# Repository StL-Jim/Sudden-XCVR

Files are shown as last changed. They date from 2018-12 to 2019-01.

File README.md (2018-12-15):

# Sudden-XCVR

These are the EagleCAD schematics and board files for the QRP Transceiver designed and built by Pete Julino N6QW called the Sudden Transceiver.  

I am very new to building a truly scratch built rig, so any suggestions, comments, corrections are greatly appreciated.

Read about the Sudden Scratch Built SSB Transceiver - http://www.n6qw.com/Sudden.html

I use a style of construction coined by Chuck Adams K7QO called 'Muppet Style', you can learn about this style of building from Chuck's YouTube channel

* https://www.youtube.com/watch?v=O6AmT1trO60

As I progress along I'll be adding PDF of the schematics and boards as well as the EagleCAD parts library I use.

73 - AE0BZ

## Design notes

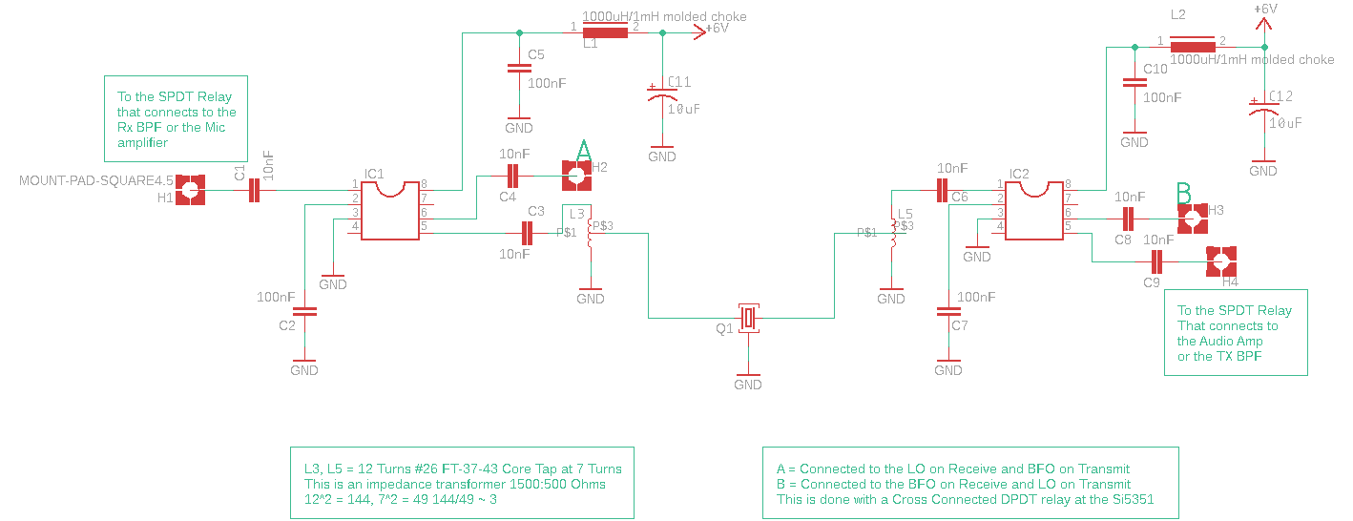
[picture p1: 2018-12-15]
Sudden_XCVR_IF_Module_Schematic.png

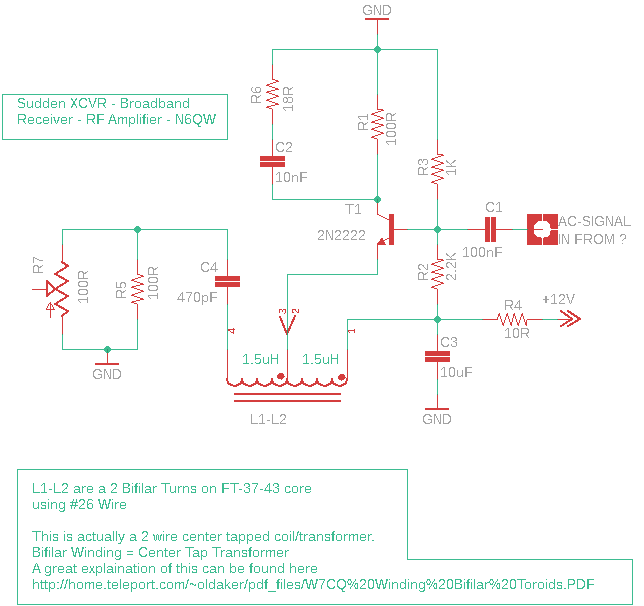
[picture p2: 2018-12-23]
broadband_receiver_rf_amp.png

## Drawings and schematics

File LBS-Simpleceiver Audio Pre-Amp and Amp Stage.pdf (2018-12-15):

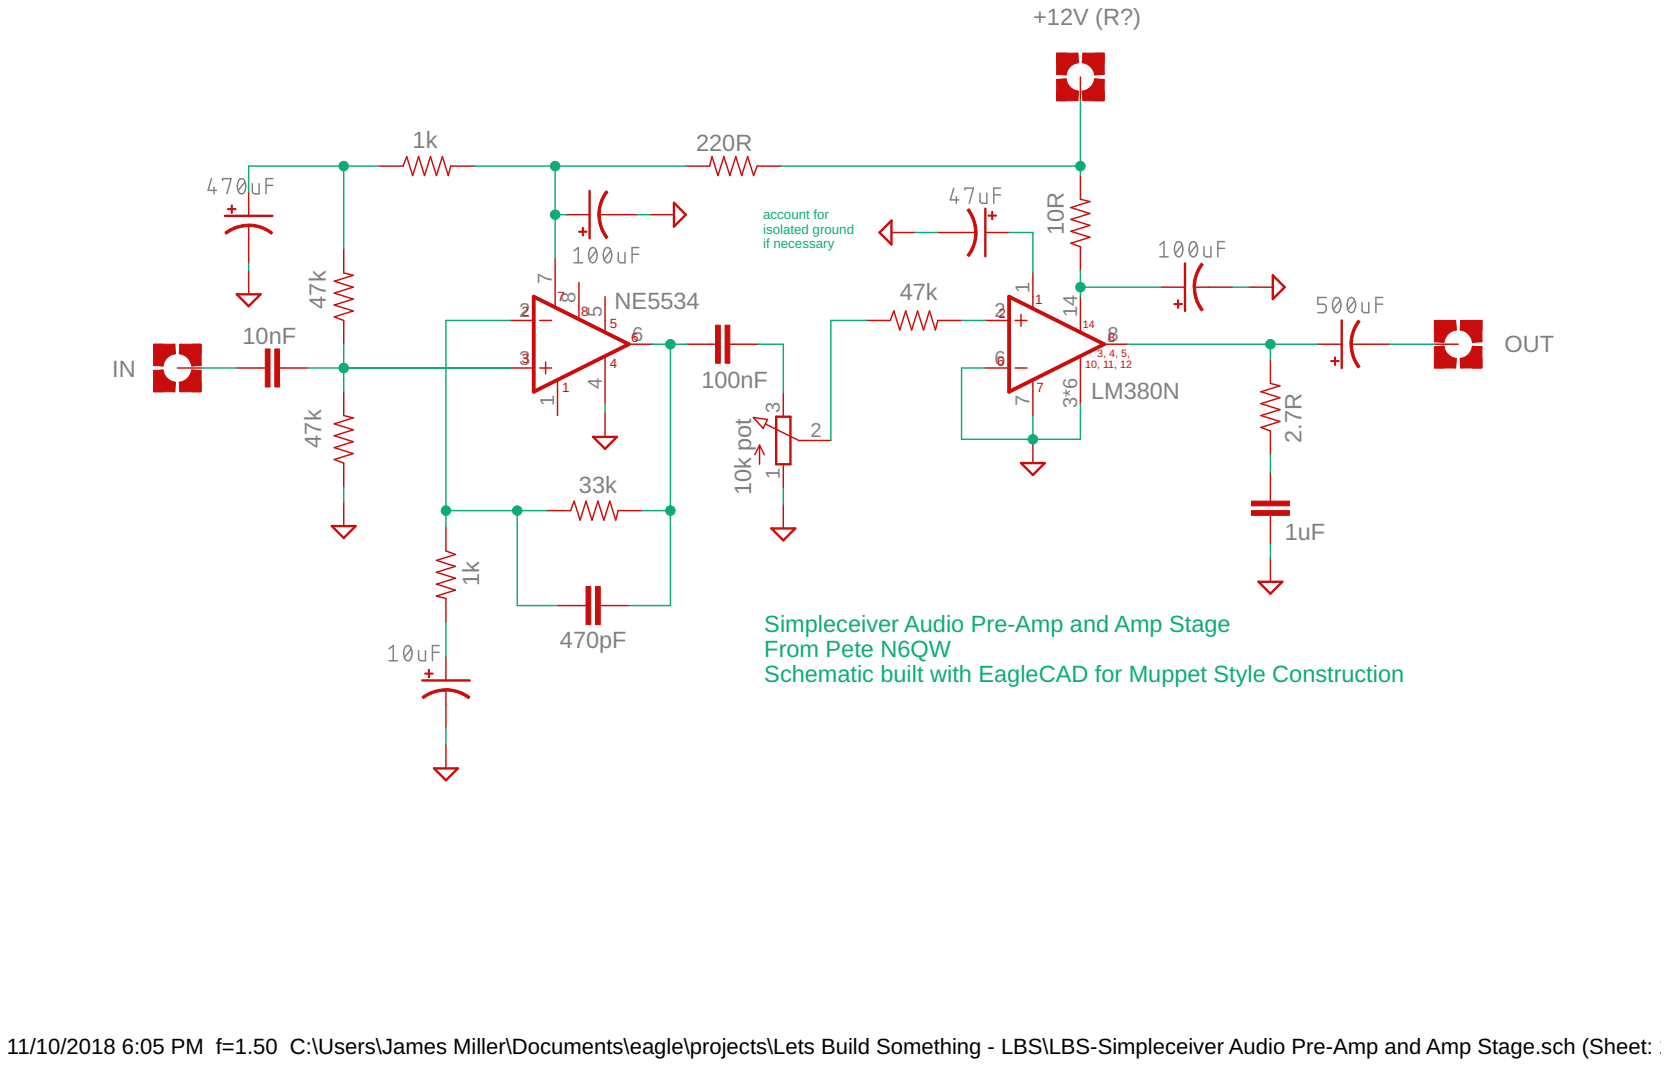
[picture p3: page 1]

Simpleceiver Audio Pre-Amp and Amp Stage
From Pete N6QW
Schematic built with EagleCAD for Muppet Style Construction

11/10/2018 6:05 PM f=1.50 C:\Users\James Miller\Documents\eagle\projects\Lets Build Something - LBS\LBS-Simpleceiver Audio Pre-Amp and Amp Stage.sch (Sheet: 1/1)

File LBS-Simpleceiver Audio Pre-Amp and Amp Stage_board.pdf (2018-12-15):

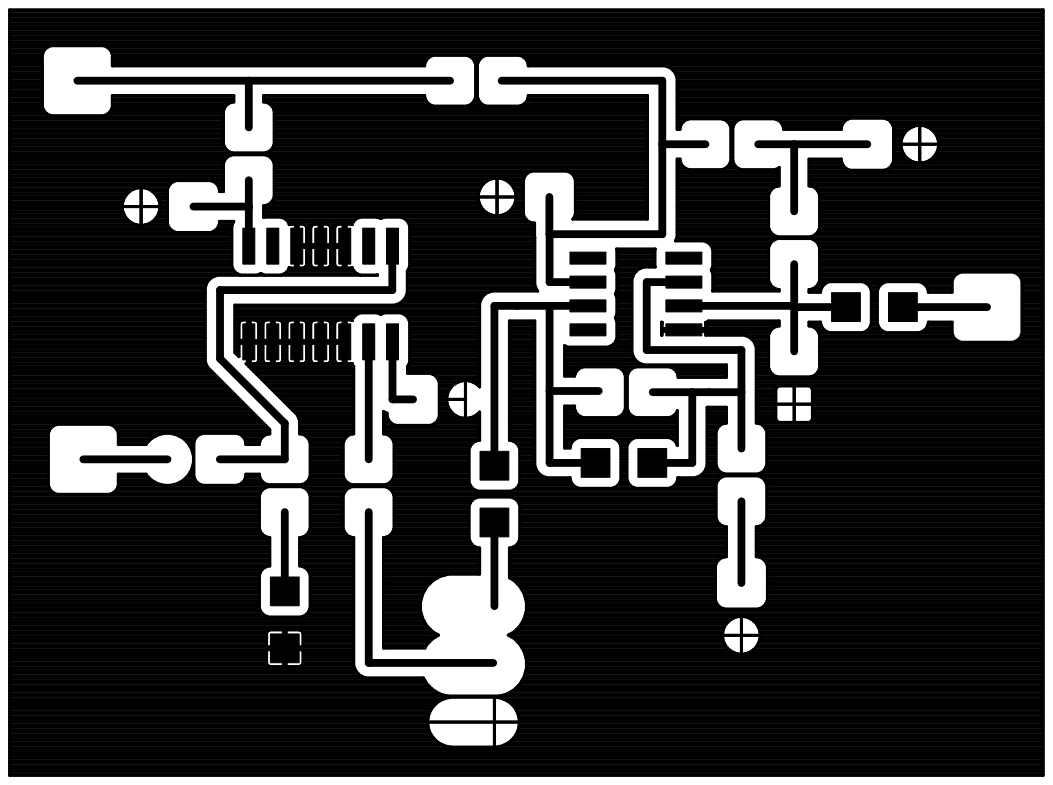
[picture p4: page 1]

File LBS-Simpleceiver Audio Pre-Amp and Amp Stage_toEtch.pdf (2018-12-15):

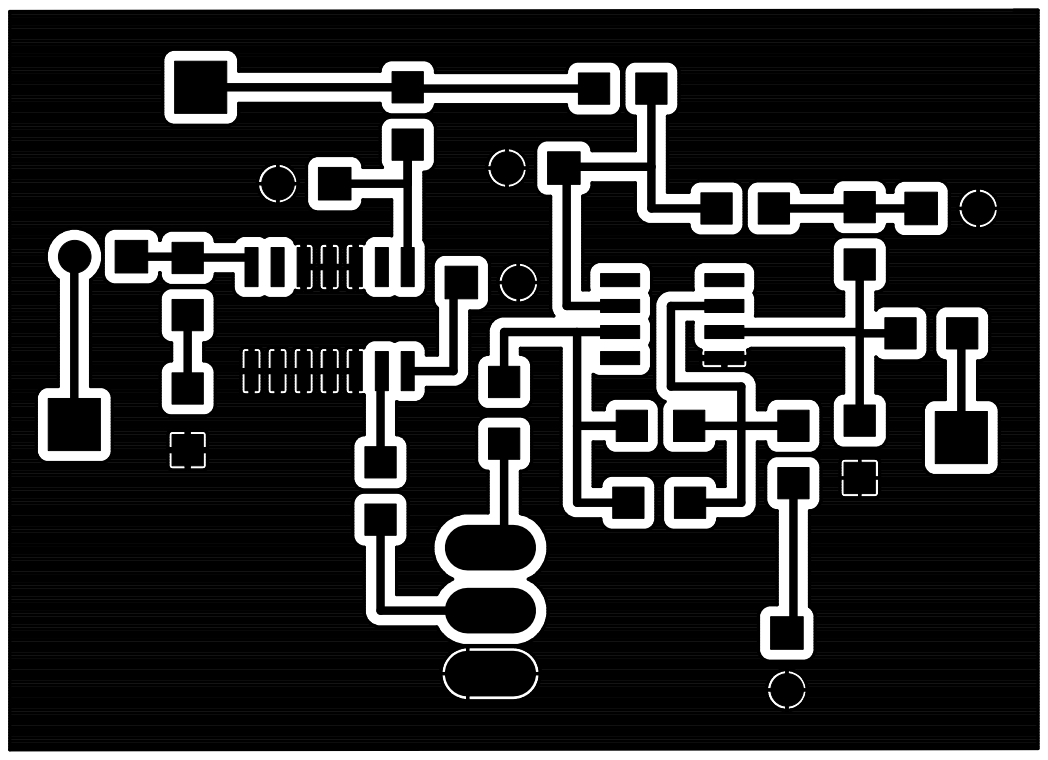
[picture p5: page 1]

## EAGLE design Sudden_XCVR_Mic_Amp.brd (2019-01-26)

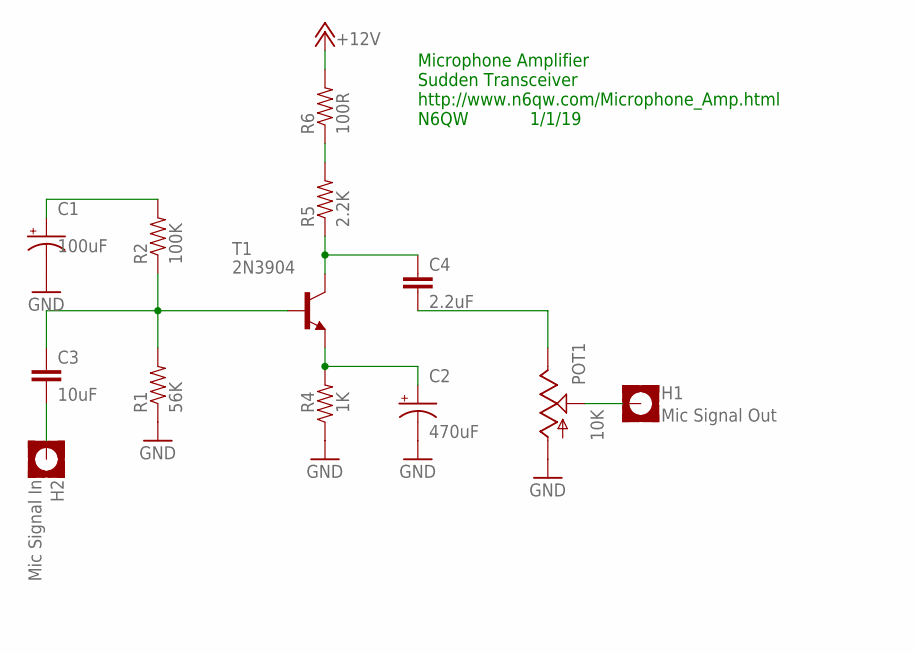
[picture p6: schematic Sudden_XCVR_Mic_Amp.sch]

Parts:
C1: 100uF; CAP-POLARIZED
C2: 470uF; CAP-POLARIZED
C3: 10uF; CAP-MEDIUM-MUPPET
C4: 2.2uF; CAP-MEDIUM-MUPPET
H1: Mic Signal Out; PAD-SQUARE
H2: Mic Signal In; PAD-SQUARE
P+1: +12V; POWER-IN-PAD
POT1: 10K; POT-TRIMM-4
R1: 56K; RESITOR-MUPPET
R2: 100K; RESITOR-MUPPET
R4: 1K; RESITOR-MUPPET
R5: 2.2K; RESITOR-MUPPET
R6: 100R; RESITOR-MUPPET
T1: 2N3904; TO92

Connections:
+12V: P+1.VCC, R6.P$2 (2)
GND: C1.2 (-), C2.2 (-), POT1.A, R1.P$1 (1), R4.P$1 (1)
unnamed: C4.1, R5.P$1 (1), T1.1 (C)
unnamed: C2.1 (+), R4.P$2 (2), T1.3 (E)
unnamed: C4.2, POT1.E
unnamed: C3.1, R1.P$2 (2), R2.P$1 (1), T1.2 (B)
unnamed: C1.1 (+), R2.P$2 (2)
unnamed: R5.P$2 (2), R6.P$1 (1)
unnamed: H1.PAD, POT1.S
unnamed: C3.2, H2.PAD

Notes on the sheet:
Microphone Amplifier Sudden Transceiver http://www.n6qw.com/Microphone_Amp.html N6QW 1/1/19

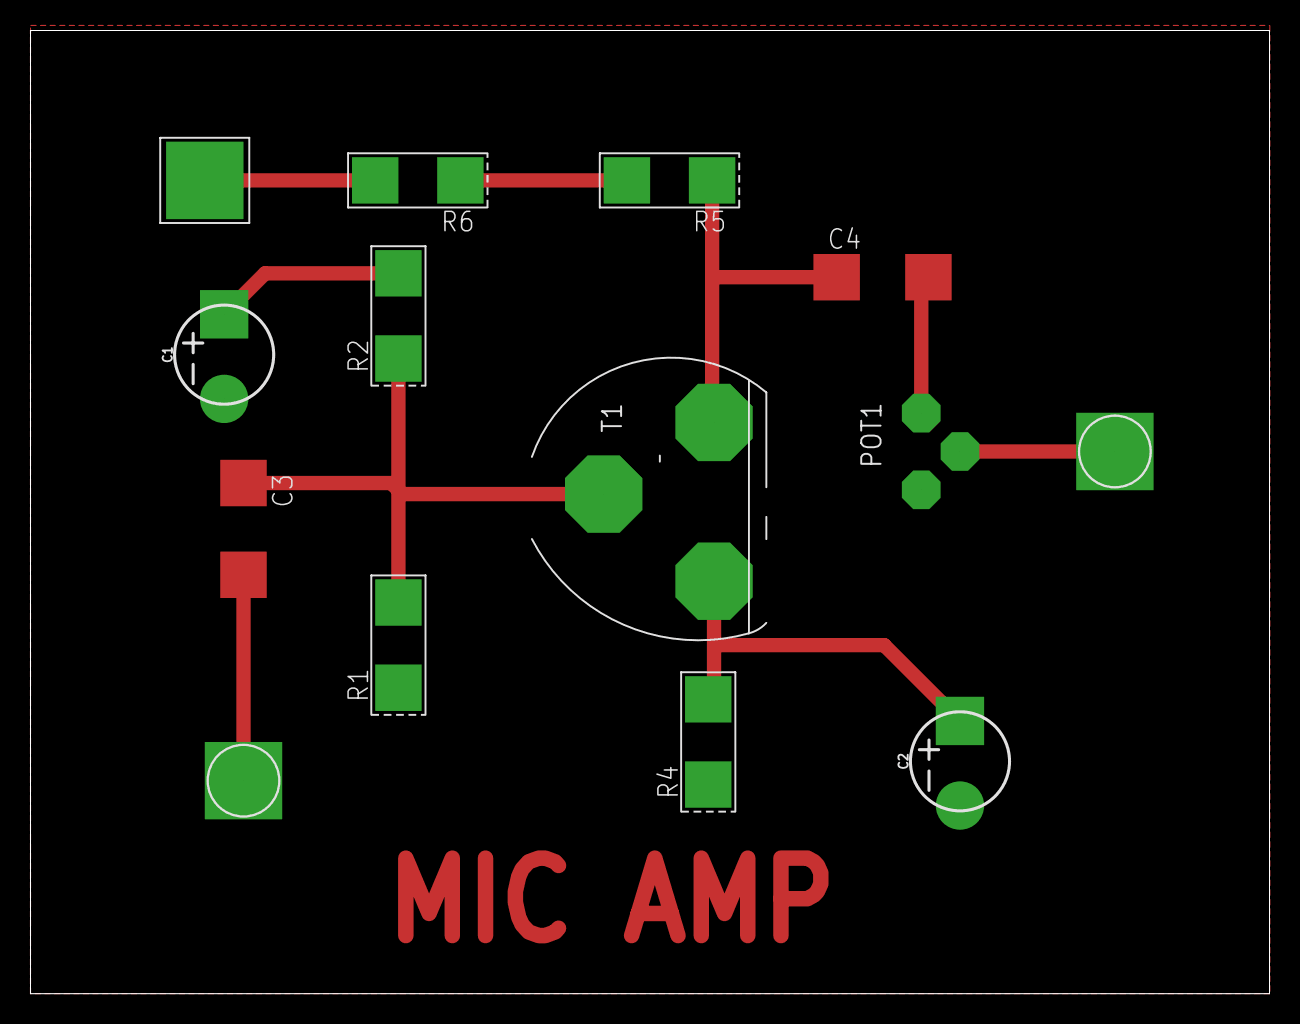
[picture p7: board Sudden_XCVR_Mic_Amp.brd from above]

Board: 2 copper layers, 81.3 x 63.2 mm, 14 parts (1 on the bottom side), 10 nets.

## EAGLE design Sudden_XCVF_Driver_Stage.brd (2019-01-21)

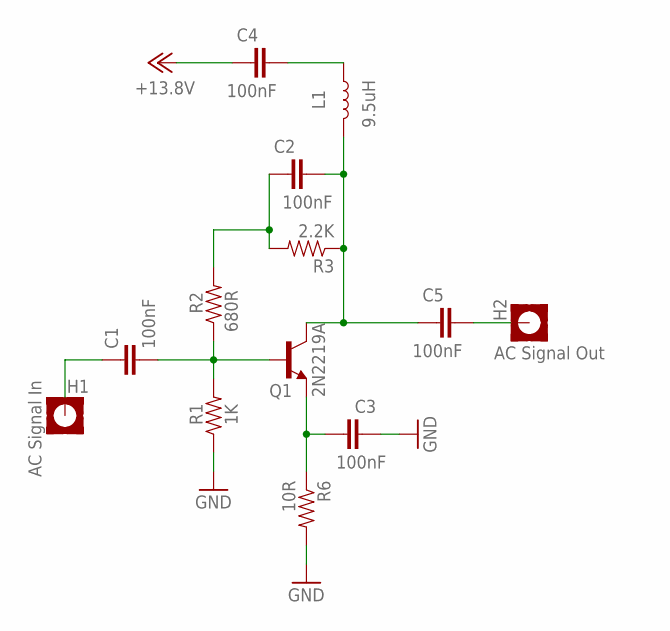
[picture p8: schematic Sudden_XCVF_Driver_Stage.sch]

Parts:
C1, C2, C3, C4, C5: 100nF; CAP-MEDIUM-MUPPET
H1: AC Signal In; PAD-SQUARE
H2: AC Signal Out; PAD-SQUARE
L1: 9.5uH; INDUCTOR_2.2UH
P+1: +13.8V; POWER-IN-PAD
Q1: 2N2219A; 2N2222-TO18
R1: 1K; RESITOR-MUPPET
R2: 680R; RESITOR-MUPPET
R3: 2.2K; RESITOR-MUPPET
R6: 10R; RESITOR-MUPPET

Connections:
+12V: C4.1, P+1.VCC
GND: C3.1, R1.P$1 (1), R6.P$2 (2)
unnamed: C1.2, Q1.2 (B), R1.P$2 (2), R2.P$1 (1)
unnamed: C2.2, C5.1, L1.P$2 (2), Q1.3 (C), R3.P$1 (1)
unnamed: C5.2, H2.PAD
unnamed: C2.1, R2.P$2 (2), R3.P$2 (2)
unnamed: C1.1, H1.PAD
unnamed: C4.2, L1.P$1 (1)
unnamed: C3.2, Q1.1 (E), R6.P$1 (1)

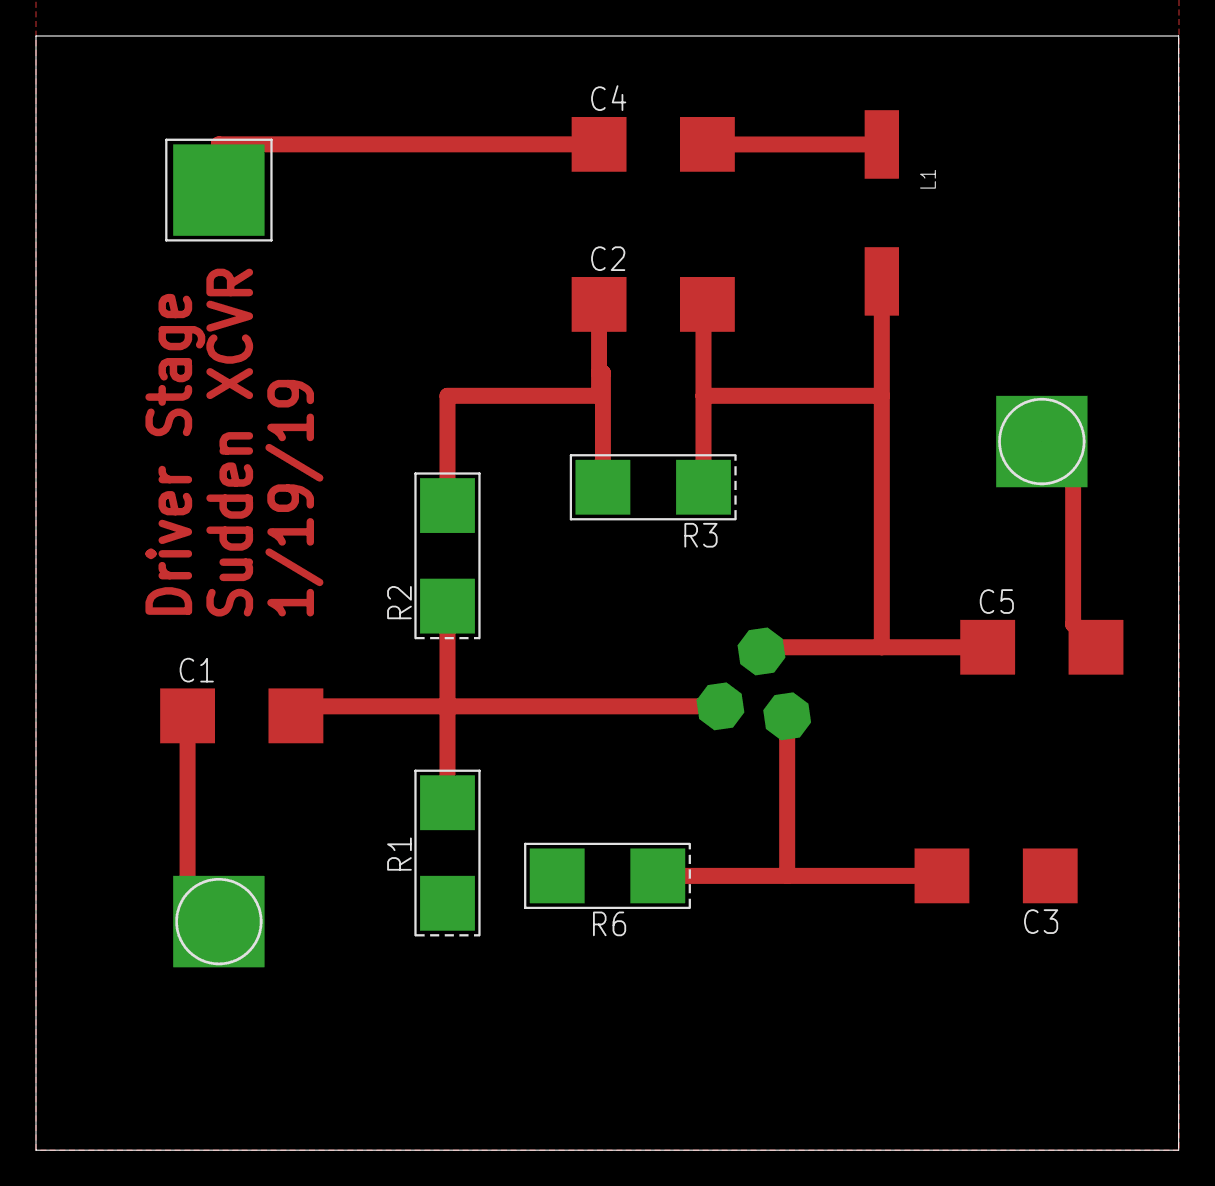
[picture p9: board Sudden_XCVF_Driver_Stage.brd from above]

Board: 2 copper layers, 63.5 x 61.9 mm, 14 parts (1 on the bottom side), 9 nets.

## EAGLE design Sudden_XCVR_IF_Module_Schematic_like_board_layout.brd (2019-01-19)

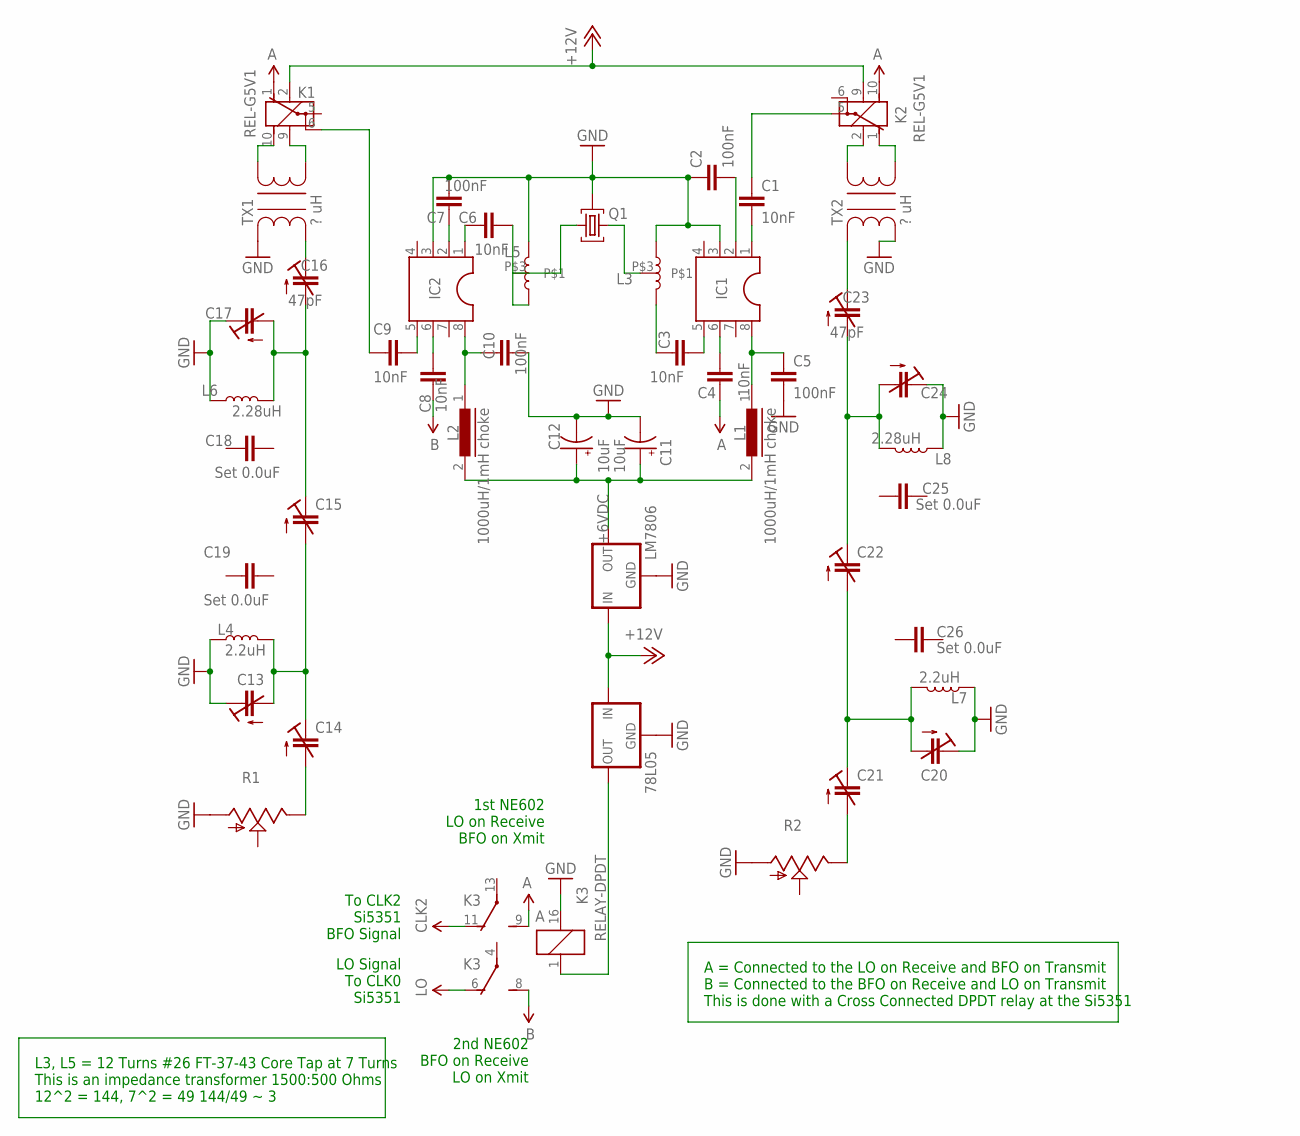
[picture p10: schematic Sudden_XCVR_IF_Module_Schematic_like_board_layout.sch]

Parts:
78L05: 78XXL
A, A1, A2: A; POWER-IN-PAD
B: B; POWER-IN-PAD
C1, C3, C4, C6, C8, C9: 10nF; CAP-MEDIUM-MUPPET
C2, C5, C7, C10: 100nF; CAP-MEDIUM-MUPPET
C11, C12: 10uF; CAP-POLARIZED
C13, C14, C15, C17, C20, C21, C22, C24: CAP-TRIMM3008; CAP-TRIMM
C16, C23: 47pF; CAP-TRIMM
C18, C19, C25, C26: Set 0.0uF; CAP-MEDIUM-MUPPET
CLK0: LO; POWER-IN-PAD
CLK1: A; POWER-IN-PAD
CLK2: CLK2; POWER-IN-PAD
IC1, IC2: DUAL-INLINE-8DIL08-2; DIL08
K1, K2: REL-G5V1; G5V1
K3: RELAY-DPDT; G5V-2
L1, L2: 1000uH/1mH choke; MOLDED-CHOKE
L3: INDUCTOR-TAPPED; INDUCTOR_TAPPED
L4, L7: 2.2uH; INDUCTOR_2.2UH
L5: INDUCTOR-TAPPED; INDUCTOR_TAPPED_MIRRORED
L6, L8: 2.28uH; INDUCTOR_2.2UH
LM7806: 78XXL
P+1, P+2: +12V; POWER-IN-PAD
Q1: CRYSTAL-FILTER
R1, R2: POTENTIOMETER-TRIMCT6; POT-TRIMM-4
SUPPLY1: B; POWER-IN-PAD
TX1, TX2: ? uH; TRANSFORMER_TWO_WIRE

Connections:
3.3V: A1.VCC, A2.VCC, B.VCC, C8.1, K1.1 (O), K2.10 (S), K3.8 (S), SUPPLY1.VCC
+6VDC: C11.1 (+), C12.1 (+), L1.2, L2.2, LM7806.OUT
+12V: 78L05.IN, K1.2 (1), K2.9 (2), LM7806.IN, P+1.VCC, P+2.VCC
A: A.VCC, C4.1, CLK0.VCC, CLK1.VCC, K3.6 (O), K3.9 (S)
BFO: CLK2.VCC, K3.11 (O)
GND: 78L05.GND, C2.1, C5.2, C7.1, C10.2, C11.2 (-), C12.2 (-), C13.+ (E), C17.+ (E), C20.+ (E), C24.+ (E), IC1.3, IC2.3, K3.16 (2), L3.P$2 (2), L4.P$1 (1), L5.P$1 (1), L6.P$1 (1), L7.P$1 (1), L8.P$1 (1), LM7806.GND, Q1.3, R1.A, R2.A, TX1.C1B (2), TX2.C1A (1)
unnamed: C5.1, IC1.8, L1.1
unnamed: C4.2, IC1.6
unnamed: C3.2, IC1.5
unnamed: L5.P$3, Q1.1
unnamed: C1.2, IC1.1
unnamed: 78L05.OUT, K3.1
unnamed: C2.2, IC1.2
unnamed: C16.+ (E), TX1.C1A (1)
unnamed: C10.1, IC2.8, L2.1
unnamed: C8.2, IC2.6
unnamed: C9.2, IC2.5
unnamed: C6.2, IC2.1
unnamed: C6.1, L5.P$2 (2)
unnamed: C7.2, IC2.2
unnamed: L3.P$3, Q1.2
unnamed: C3.1, L3.P$1 (1)
unnamed: C1.1, K2.5
unnamed: C9.1, K1.6
unnamed: C15.+ (E), C16.- (A), C17.- (A), L6.P$2 (2)
unnamed: C14.- (A), R1.E
unnamed: C13.- (A), C14.+ (E), C15.- (A), L4.P$2 (2)
unnamed: C23.+ (E), TX2.C1B (2)
unnamed: C22.+ (E), C23.- (A), C24.- (A), L8.P$2 (2)
unnamed: C20.- (A), C21.+ (E), C22.- (A), L7.P$2 (2)
unnamed: C21.- (A), R2.E
unnamed: K1.9 (2), TX1.C2A (5)
unnamed: K1.10 (S), TX1.C2B (6)
unnamed: K2.2 (1), TX2.C2B (6)
unnamed: K2.1 (O), TX2.C2A (5)

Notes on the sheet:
L3, L5 = 12 Turns #26 FT-37-43 Core Tap at 7 Turns This is an impedance transformer 1500:500 Ohms 12^2 = 144, 7^2 = 49 144/49 ~ 3
A = Connected to the LO on Receive and BFO on Transmit B = Connected to the BFO on Receive and LO on Transmit This is done with a Cross Connected DPDT relay at the Si5351
1st NE602 LO on Receive BFO on Xmit
2nd NE602 BFO on Receive LO on Xmit
LO Signal To CLK0 Si5351
To CLK2 Si5351 BFO Signal

Board: 2 copper layers, 56 parts (0 on the bottom side), 35 nets, no tracks yet.

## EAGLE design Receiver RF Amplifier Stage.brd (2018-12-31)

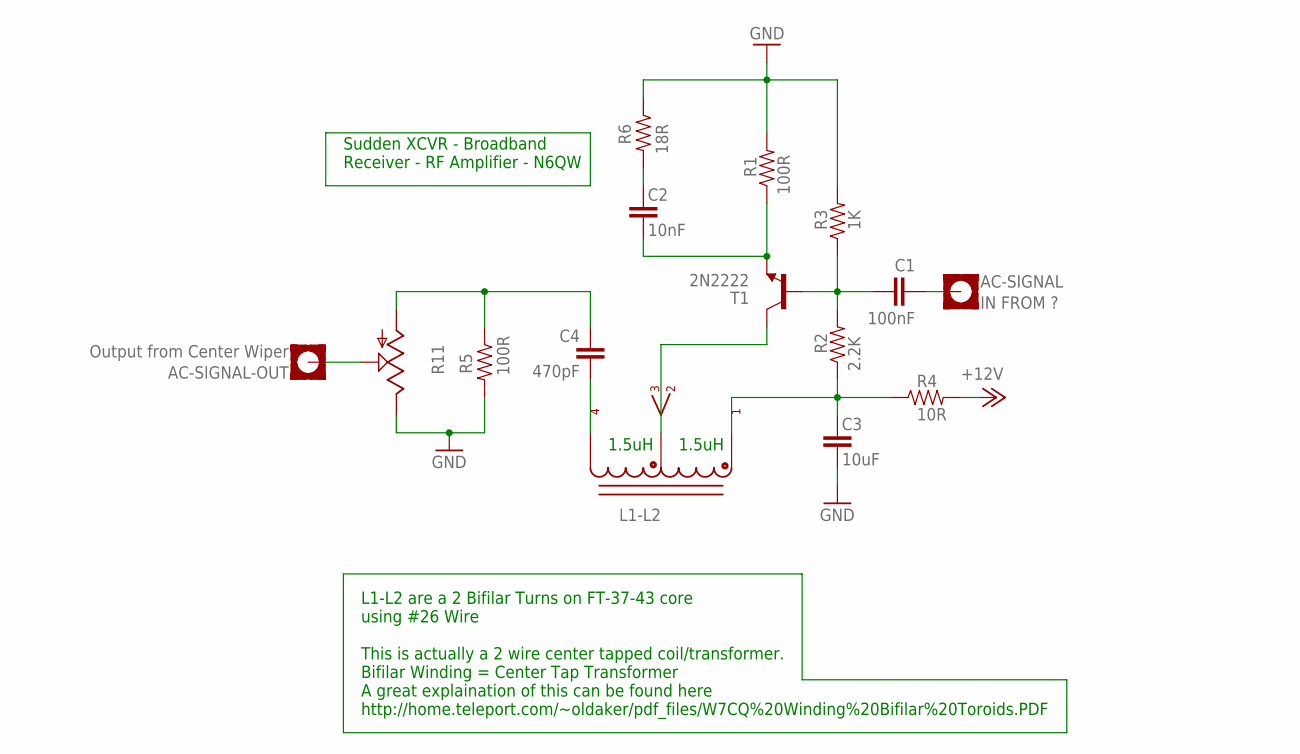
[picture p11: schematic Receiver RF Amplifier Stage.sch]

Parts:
AC-SIGNAL: IN FROM ?; PAD-SQUARE
AC-SIGNAL-OUT: Output from Center Wiper; PAD-SQUARE
C1: 100nF; CAP-MEDIUM-MUPPET
C2: 10nF; CAP-MEDIUM-MUPPET
C3: 10uF; CAP-MEDIUM-MUPPET
C4: 470pF; CAP-MEDIUM-MUPPET
L1-L2: T37-43_BIFILAR_TORIODBIFILAR-COIL/TRANSFORMER; T37-43_BIFILAR_TOROID
P+1: +12V; POWER-IN-PAD
R1, R5: 100R; RESITOR-MUPPET
R2: 2.2K; RESITOR-MUPPET
R3: 1K; RESITOR-MUPPET
R4: 10R; RESITOR-MUPPET
R6: 18R; RESITOR-MUPPET
R11: POTENTIOMETER-TRIMCT6; POT-TRIMM-4
T1: 2N2222; 2N2222-TO18

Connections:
+12V: P+1.VCC, R4.P$2 (2)
GND: C3.1, R1.P$2 (2), R3.P$2 (2), R5.P$2 (2), R6.P$1 (1), R11.E
unnamed: C1.1, R2.P$2 (2), R3.P$1 (1), T1.2 (B)
unnamed: AC-SIGNAL-OUT.PAD, R11.S
unnamed: C2.2, R6.P$2 (2)
unnamed: L1-L2.C2A, T1.3 (C)
unnamed: C4.1, L1-L2.C3A
unnamed: C3.2, L1-L2.C1A, R2.P$1 (1), R4.P$1 (1)
unnamed: C4.2, R5.P$1 (1), R11.A
unnamed: AC-SIGNAL.PAD, C1.2
unnamed: C2.1, R1.P$1 (1), T1.1 (E)

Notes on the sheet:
Sudden XCVR - Broadband Receiver - RF Amplifier - N6QW
L1-L2 are a 2 Bifilar Turns on FT-37-43 core using #26 Wire This is actually a 2 wire center tapped coil/transformer. Bifilar Winding = Center Tap Transformer A great explaination of this can be found here http://home.teleport.com/~oldaker/pdf_files/W7CQ%20Winding%20Bifilar%20Toroids.PDF
1.5uH

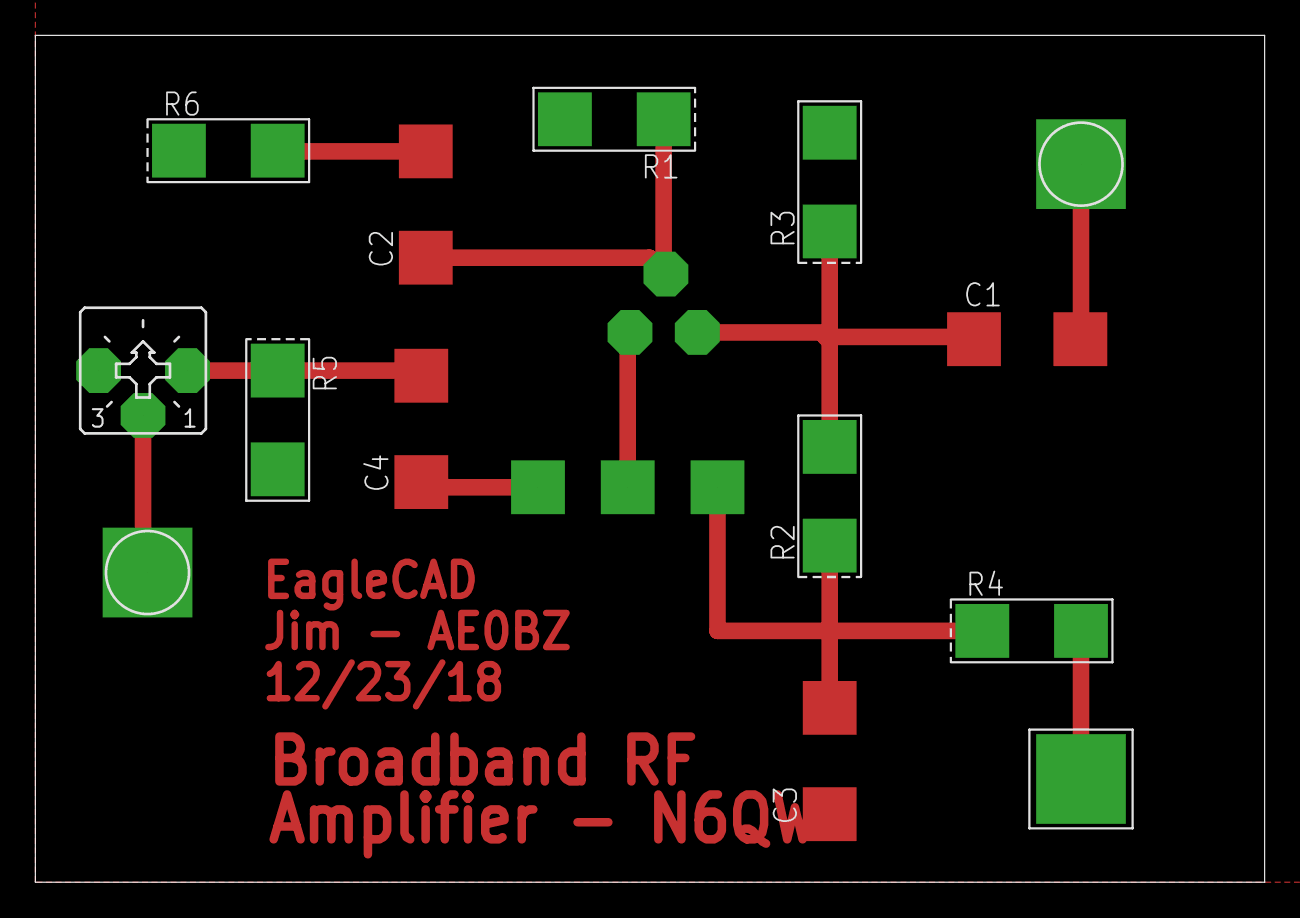
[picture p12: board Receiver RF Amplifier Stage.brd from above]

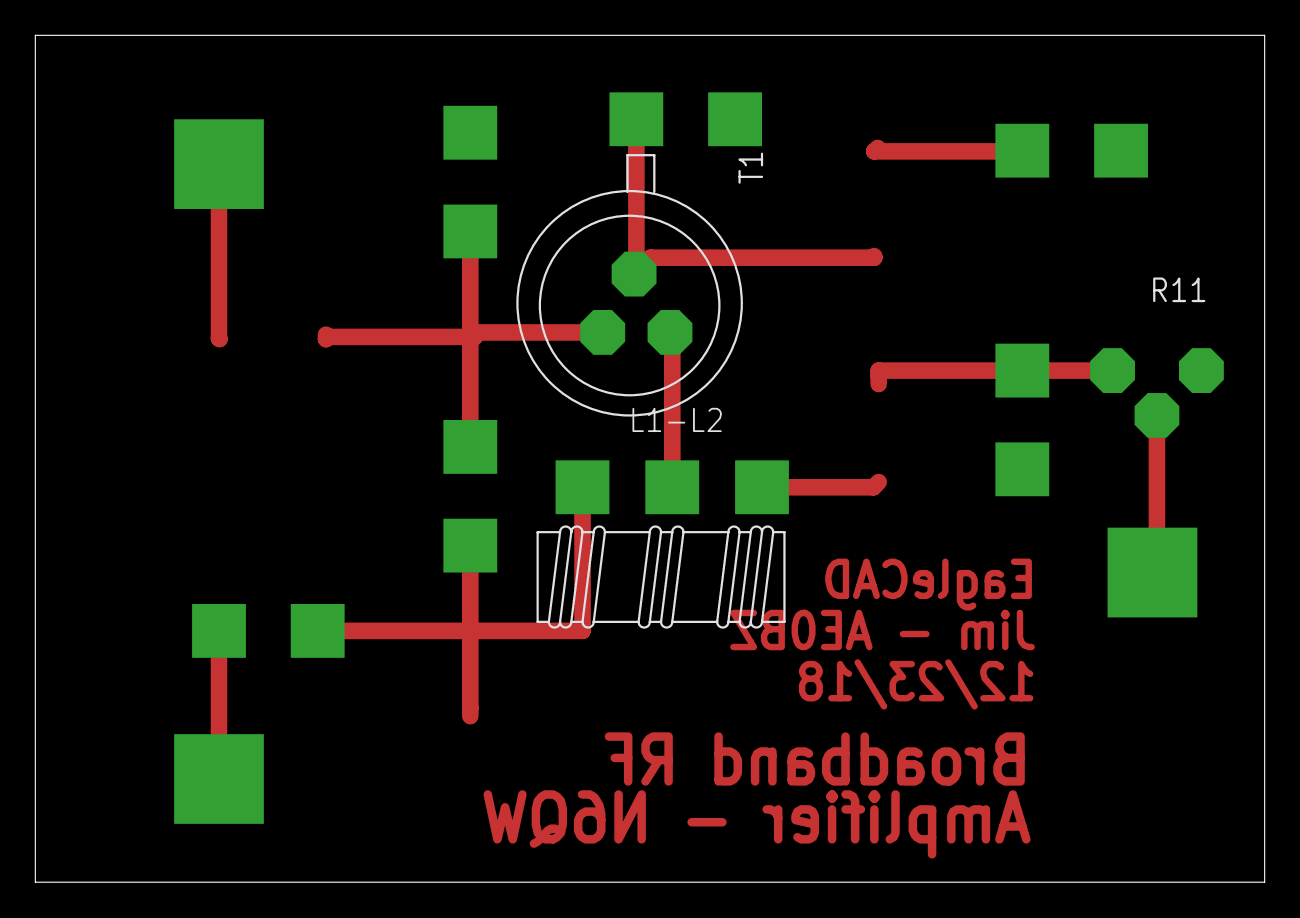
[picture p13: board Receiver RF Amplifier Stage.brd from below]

Board: 2 copper layers, 69.6 x 47.9 mm, 16 parts (2 on the bottom side), 11 nets.

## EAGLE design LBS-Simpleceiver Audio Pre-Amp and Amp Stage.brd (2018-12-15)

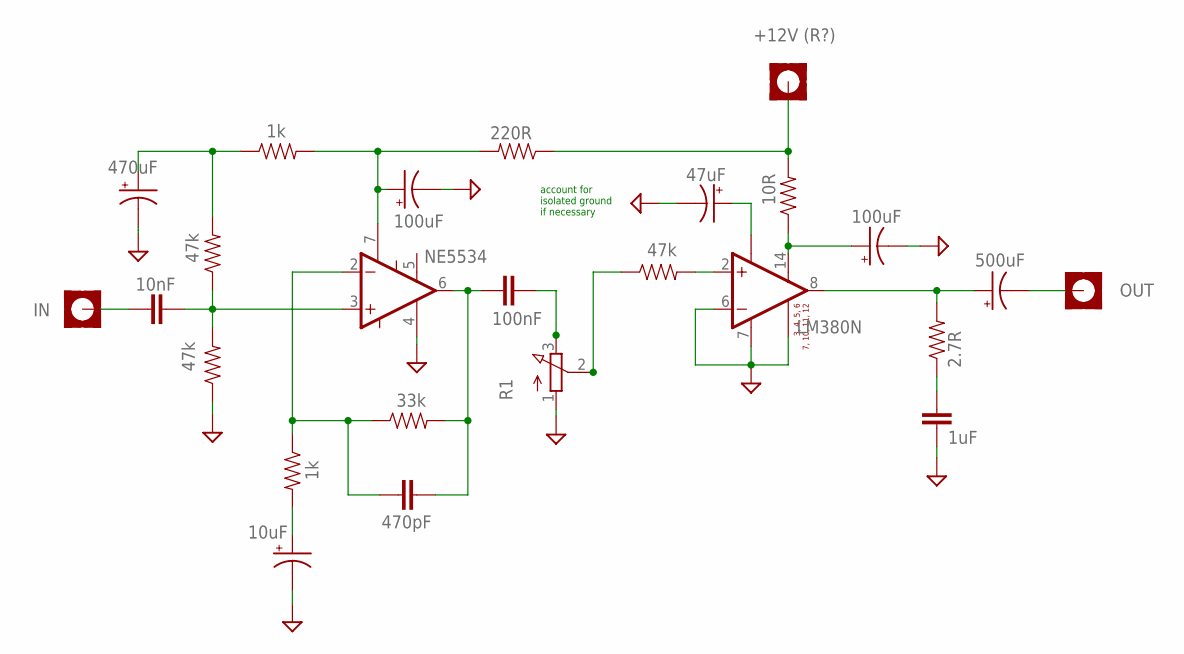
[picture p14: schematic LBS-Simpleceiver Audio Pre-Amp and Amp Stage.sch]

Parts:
C1: 470uF; CAP-POLARIZED
C2, C6: 100uF; CAP-POLARIZED
C3: 500uF; CAP-POLARIZED
C4: 47uF; CAP-POLARIZED
C5: 10uF; CAP-POLARIZED
C7: 10nF; CAP-MEDIUM-MUPPET
C8: 100nF; CAP-MEDIUM-MUPPET
C9: 1uF; CAP-MEDIUM-MUPPET
C10: 470pF; CAP-MEDIUM-MUPPET
H1: IN; PAD-SQUARE
H2: OUT; PAD-SQUARE
H3: +12V (R?); PAD-SQUARE
IC1: NE5534; DIL08
R1: POTENTIOMETER
R2, R3: 47k; RESITOR-MUPPET
R4: 1k; RESITOR-MUPPET
R5: 33k; RESITOR-MUPPET
R8: 220R; RESITOR-MUPPET
R9: 2.7R; RESITOR-MUPPET
U1: LM380N; DIL14
U$4: 1k; RESITOR-MUPPET
U$6: 47k; RESITOR-MUPPET
U$7: 10R; RESITOR-MUPPET

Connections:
GND: C1.2 (-), C2.2 (-), C4.2 (-), C5.2 (-), C6.2 (-), C9.2, IC1.4 (VCC-GND), R1.1 (A), R3.P$1 (1), U1.3 (GND), U1.4 (GND), U1.5 (GND), U1.6 (-IN), U1.7 (GND1), U1.10 (GND), U1.11 (GND), U1.12 (GND)
unnamed: C7.1, H1.PAD
unnamed: C7.2, IC1.3 (+IN), R2.P$1 (1), R3.P$2 (2)
unnamed: C1.1 (+), R2.P$2 (2), R4.P$1 (1)
unnamed: C6.1 (+), IC1.7 (VCC+), R4.P$2 (2), R8.P$2 (2)
unnamed: C8.2, C10.1, IC1.6 (OUT), R5.P$2 (2)
unnamed: C10.2, IC1.2 (-IN), R5.P$1 (1), U$4.P$1 (1)
unnamed: C5.1 (+), U$4.P$2 (2)
unnamed: C8.1, R1.3 (E)
unnamed: R1.2 (S), U$6.P$1 (1)
unnamed: U1.2 (+IN), U$6.P$2 (2)
unnamed: C2.1 (+), U1.14 (V-SIG), U$7.P$1 (1)
unnamed: H3.PAD, R8.P$1 (1), U$7.P$2 (2)
unnamed: C3.1 (+), R9.P$2 (2), U1.8 (GAIN)
unnamed: C9.1, R9.P$1 (1)
unnamed: C4.1 (+), U1.1 (BYPASS)
unnamed: C3.2 (-), H2.PAD

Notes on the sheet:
account for isolated ground if necessary

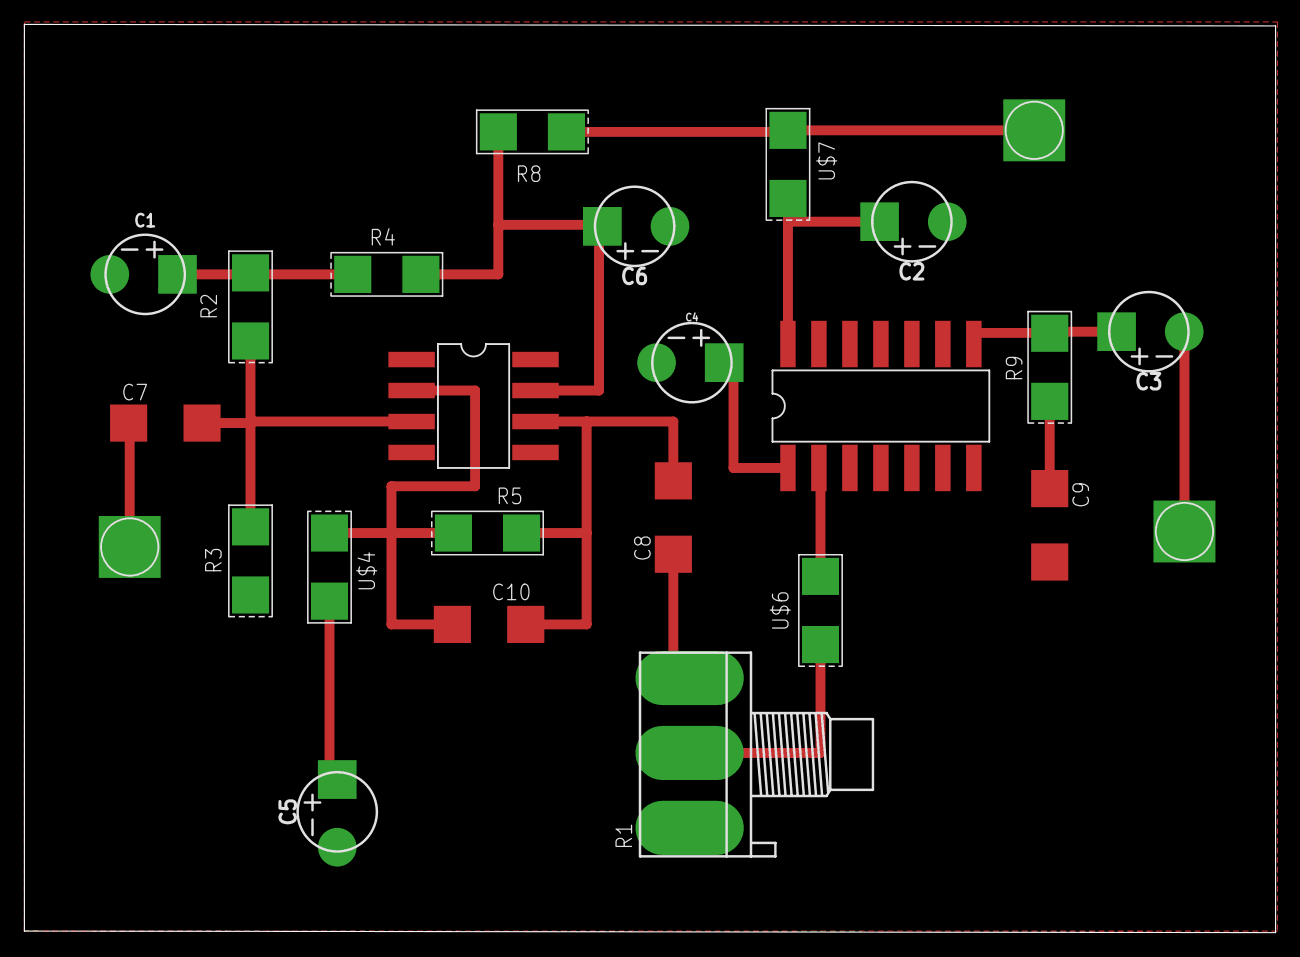
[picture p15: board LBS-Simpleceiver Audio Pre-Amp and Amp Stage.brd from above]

Board: 2 copper layers, 102.6 x 74.5 mm, 25 parts (0 on the bottom side), 17 nets.

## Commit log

2018-12-15 Initial commit of Sudden XCVR On branch master Changes to be committed: new file: LBS-Simpleceiver Audio Pre-Amp and Amp Stage.b#1 new file: LBS-Simpleceiver Audio Pre-Amp and Amp Stage.b#2 new file: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
    [LBS-Simpleceiver Audio Pre-Amp and Amp Stage.brd, LBS-Simpleceiver Audio Pre-Amp and Amp Stage.sch, Receiver RF Amplifier Stage.brd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]
2018-12-15 Adding some images as well as updates
    Adding some images as well as updates to the Receiver RF Amplifier Stage
    [Receiver RF Amplifier Stage.sch]
2018-12-23 Updated schematic to have a bifilar winding
    Updated schematic to have a bifilar winding or center tapped
    transformer.
    Also starting to work on the board.
    On branch master
    Your branch is up-to-date with 'origin/master'.
    Changes to be committed:
    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
    [Receiver RF Amplifier Stage.brd, Receiver RF Amplifier Stage.sch]
2018-12-31 Lots of changes.
    Recreated the IF Schema and a new board to look like the photo
    modified: Receiver RF Amplifier Stage.b#1
    modified: Receiver RF Amplifier Stage.b#2
    modified: Receiver RF Amplifier Stage.b#3
    modified: Receiver RF Amplifier Stage.b#4
    modified: Receiver RF Amplifier Stage.b#5
    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
    [Receiver RF Amplifier Stage.brd, Receiver RF Amplifier Stage.sch, Sudden_XCVR_IF_Module.brd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]
2019-01-02 Added Pre-Driver and Mic Amp
    Added Pre-Driver and Mic Amp
    new file: Sudden_XCVF_Transmit_Pre-Driver_Stage.s#1
    new file: Sudden_XCVF_Transmit_Pre-Driver_Stage.sch
    new file: Sudden_XCVR_Mic_Amp.b#1
    new file: Sudden_XCVR_Mic_Amp.b#2
    new file: Sudden_XCVR_Mic_Amp.brd
    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
    [Sudden_XCVF_Transmit_Pre-Driver_Stage.sch, Sudden_XCVR_Mic_Amp.brd, Sudden_XCVR_Mic_Amp.sch]
2019-01-06 Added additional schematics and board layout
    Added additional schmentics and board layout for Driver stage and a new IF schematic and board
    [Sudden_XCVF_Driver_Stage.brd, Sudden_XCVF_Driver_Stage.sch, Sudden_XCVR_IF_Module_Schematic_like_board_layout.brd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]
2019-01-19 Updated the IF module - mainly board layout
    Updated the IF module - mainly board layout
    [Sudden_XCVR_IF_Module_Schematic_like_board_layout.brd, Sudden_XCVR_IF_Module_Schematic_like_board_layout.sch]
2019-01-19 Still needed traces for Mic Amp board
    modified: Sudden_XCVF_Driver_Stage.b#1
    modified: Sudden_XCVF_Driver_Stage.b#2
    modified: Sudden_XCVF_Driver_Stage.b#3
    new file: Sudden_XCVF_Driver_Stage.b#4
    new file: Sudden_XCVF_Driver_Stage.b#5
    modified: Sudden_XCVF_Driver_Stage.brd
    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
    [Sudden_XCVF_Driver_Stage.brd]
2019-01-21 On branch master Changes to be committed: modified: Sudden_XCVF_Driver_Stage.b#1 modified: Sudden_XCVF_Driver_Stage.b#2 modified: Sudden_XCVF_Driver_Stage.b#3 modified: Sudden_XCVF_Driver_Stage.b#4 m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
    [Sudden_XCVF_Driver_Stage.brd, Sudden_XCVF_Driver_Stage.sch]
2019-01-21 Added Mic Amp
    Added Mic Amp, not sure this will conflict with previous commit
    modified: Sudden_XCVR_Mic_Amp.b#1
    modified: Sudden_XCVR_Mic_Amp.b#2
    modified: Sudden_XCVR_Mic_Amp.b#3
    new file: Sudden_XCVR_Mic_Amp.b#4
    modified: Sudden_XCVR_Mic_Amp.brd
    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
    [Sudden_XCVR_Mic_Amp.brd]
2019-03-17 Place to put DC Circuits Class Labs
    Place to put DC Circuits Class Labs
    new file: DC Circuits Class/BreadBoard_Simple_Parallel_Resistive_Circuit.s#1
    new file: DC Circuits Class/BreadBoard_Simple_Parallel_Resistive_Circuit.s#2
    new file: DC Circuits Class/BreadBoard_Simple_Parallel_Resistive_Circuit.sch
    new file: DC Circuits Class/BreadBoard_Simple_Serial_Resistive_Circuit.sch
    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
    [BreadBoard_Simple_Parallel_Resistive_Circuit.sch, BreadBoard_Simple_Serial_Resistive_Circuit.sch]

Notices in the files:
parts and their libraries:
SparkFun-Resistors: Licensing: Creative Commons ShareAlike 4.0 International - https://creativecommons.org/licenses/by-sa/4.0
